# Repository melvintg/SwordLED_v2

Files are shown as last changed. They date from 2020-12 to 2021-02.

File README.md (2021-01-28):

# SwordLED_v2
Arduino LED system embeded in a softcombat sword.
Features:
- BMS for 2S 18650 batteries with automatic cell balance.
- 2S 18650 charger (Vin=12V).
- 5V Buck converter up to 3A
- Arduino ATmega328P with USB
- Bluetooth module HC-06
- 3 axis Accel/gyro MPU-6050
- Touch sensitive button & beeper.

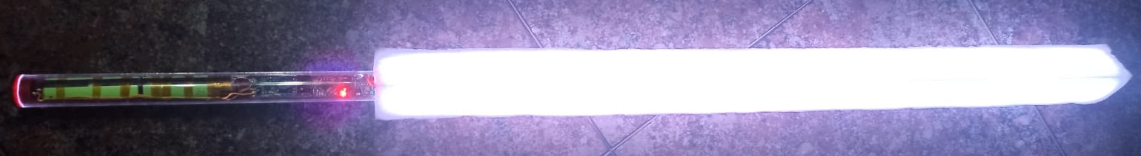
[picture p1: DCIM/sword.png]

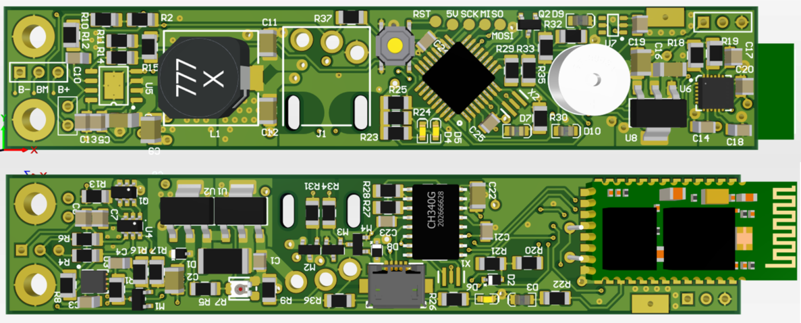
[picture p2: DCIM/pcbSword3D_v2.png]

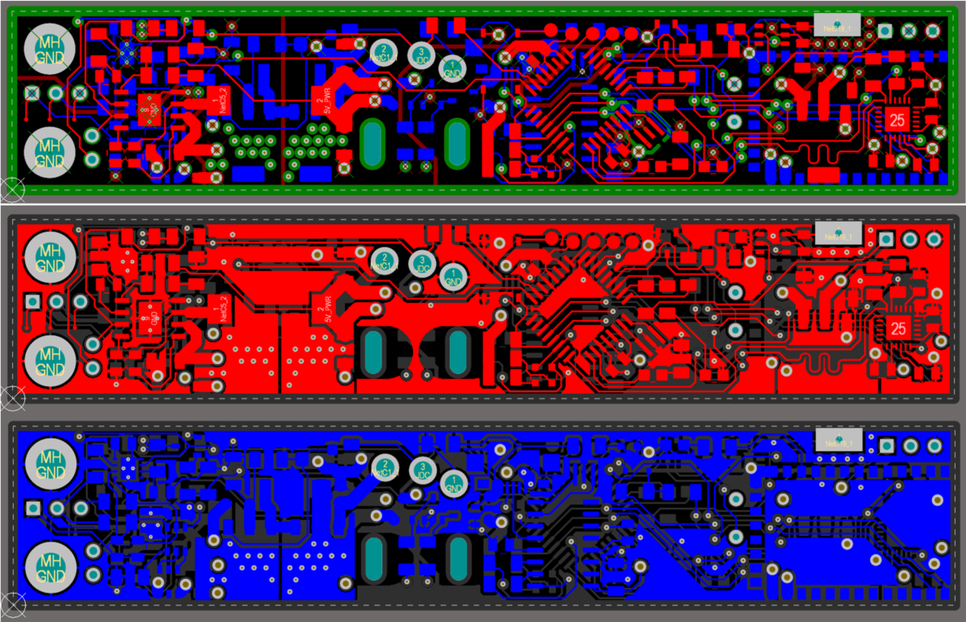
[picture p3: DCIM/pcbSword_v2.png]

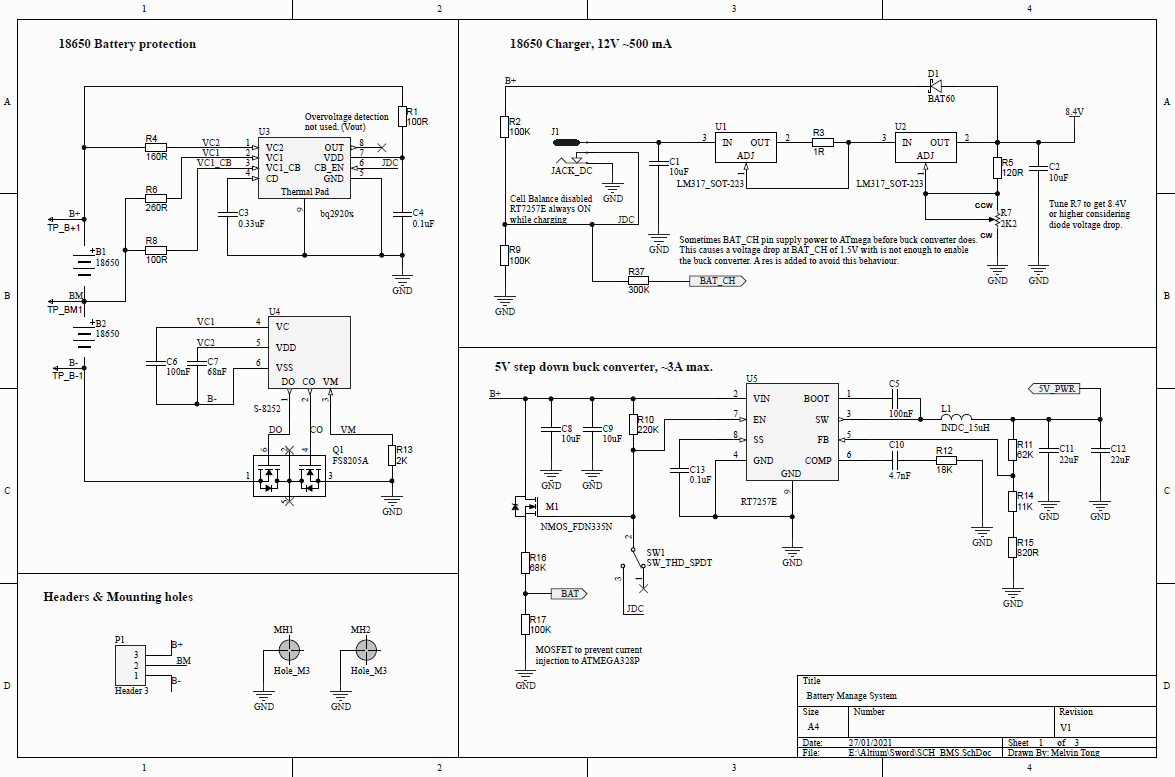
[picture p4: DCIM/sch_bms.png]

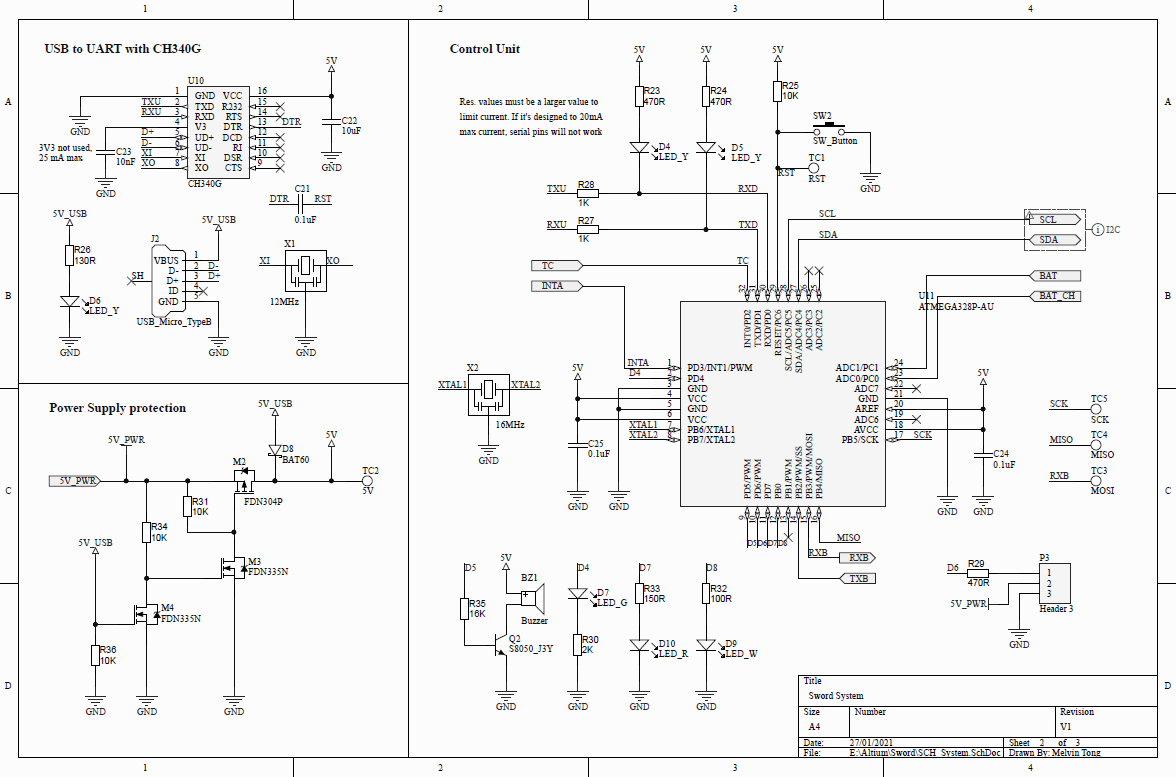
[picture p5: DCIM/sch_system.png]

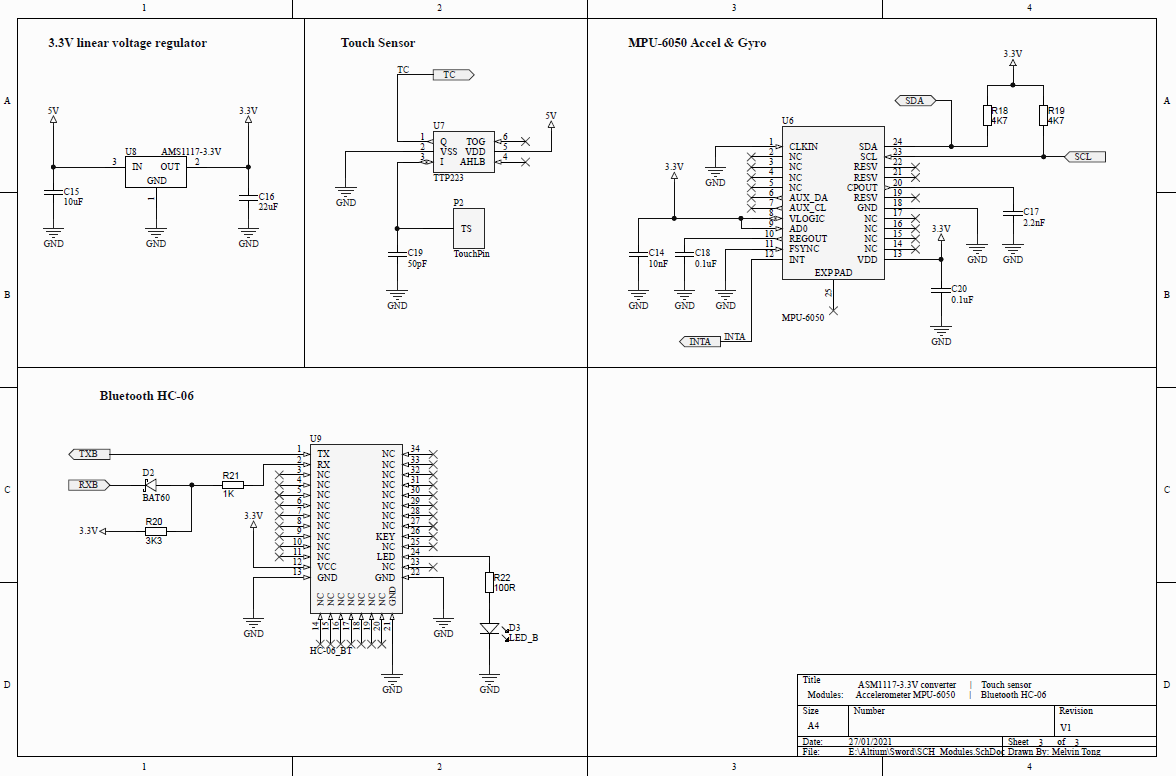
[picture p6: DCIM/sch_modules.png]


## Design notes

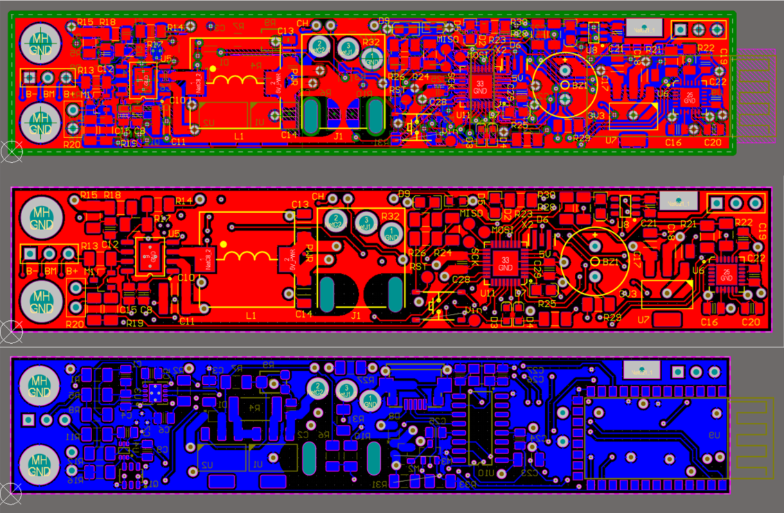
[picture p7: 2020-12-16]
DCIM/pcbSword.png

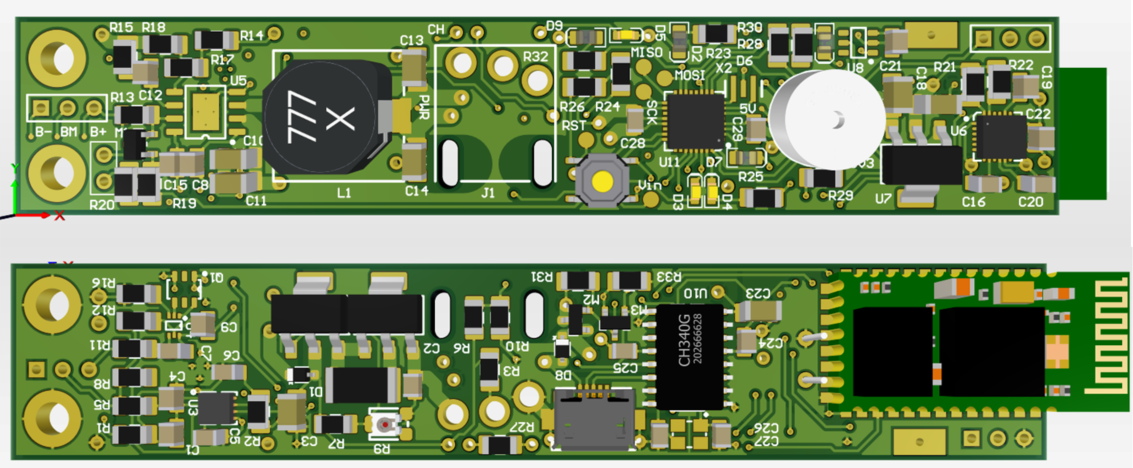
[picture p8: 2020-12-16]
DCIM/pcbSword3D.png

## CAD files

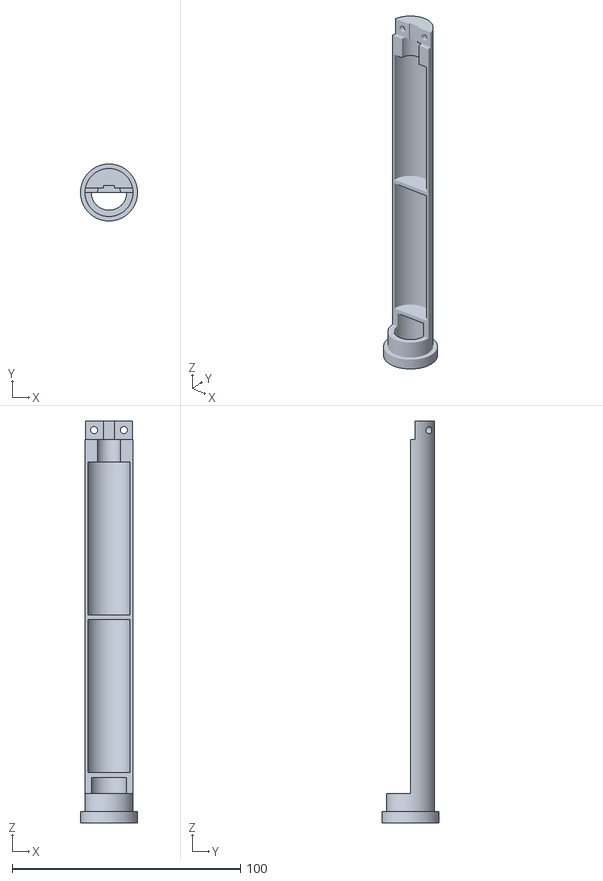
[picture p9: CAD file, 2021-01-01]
OpenSCADFiles/Sword.stl
25.0 x 25.0 x 176.0

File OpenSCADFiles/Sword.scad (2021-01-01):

$fn = 100;

// Variable declarations
dBase = 25;
hBase = 5;
dInnerBase = 21; // 25 - 2.8x2 thickness

dSW = 15.5;
dCapSW = 17;
hCapSW = 1.6;
hSW = 13;
hPinSW = 20;

hBat = 67;
dBat = 18.6;
dPinBat = 10;
hPinBat = 10;
hGapBat = 2;

yPcbGap = 2;
hPcbGap = 8;
pins2pcbGap = 8;
pinsHole = dInnerBase - pins2pcbGap*2;
hole2pcbGap = 4;
M3HoleCenter = (dInnerBase/2) - hole2pcbGap;
dM3Hole = 3.1;

hTotal = hPinSW+hBat*2+hGapBat*2+hPinBat+hPcbGap;


module Slot() {
    difference(){
    cylinder(h=hTotal,d=dInnerBase);
    translate([-dInnerBase/2,-dInnerBase,hSW])
        cube([dInnerBase,dInnerBase,hTotal]);
    }
}


module SW() {
    union(){
        cylinder(h=hPinSW,d=dSW);
        cylinder(h=hCapSW,d=dCapSW);
    }
}

module Base() {
    cylinder(h=hBase,d=dBase);
}

module Batteries() {
    translate([0,0,hPinSW+hGapBat])
        cylinder(h=hBat,d=dBat);
    translate([0,0,hPinSW+hGapBat*2+hBat])
        cylinder(h=hBat,d=dBat);
    translate([0,0,hPinSW+hGapBat*2+hBat*2])
        cylinder(h=hPinBat,d=dPinBat);
    
}

module PCB(){
    translate([-M3HoleCenter,dInnerBase/2,hTotal-hole2pcbGap])
        rotate([90,90,0])
            cylinder(h=dInnerBase,d=dM3Hole);
    translate([M3HoleCenter,dInnerBase/2,hTotal-hole2pcbGap])
        rotate([90,90,0])
            cylinder(h=dInnerBase,d=dM3Hole);
    translate([0,yPcbGap/2,hTotal-hPcbGap/2])
        cube([dInnerBase,yPcbGap,hPcbGap],true);
    translate([0,yPcbGap,hTotal-hPcbGap/2])
        cube([pinsHole,2,hPcbGap],true);
    
}

difference(){
    union(){
        Slot();
        Base();
    }
    SW();
    Batteries();
    PCB();
    /*
    translate([-dBase/2,-dInnerBase,0])
        cube([dBase,dInnerBase,hTotal]);
    */
}

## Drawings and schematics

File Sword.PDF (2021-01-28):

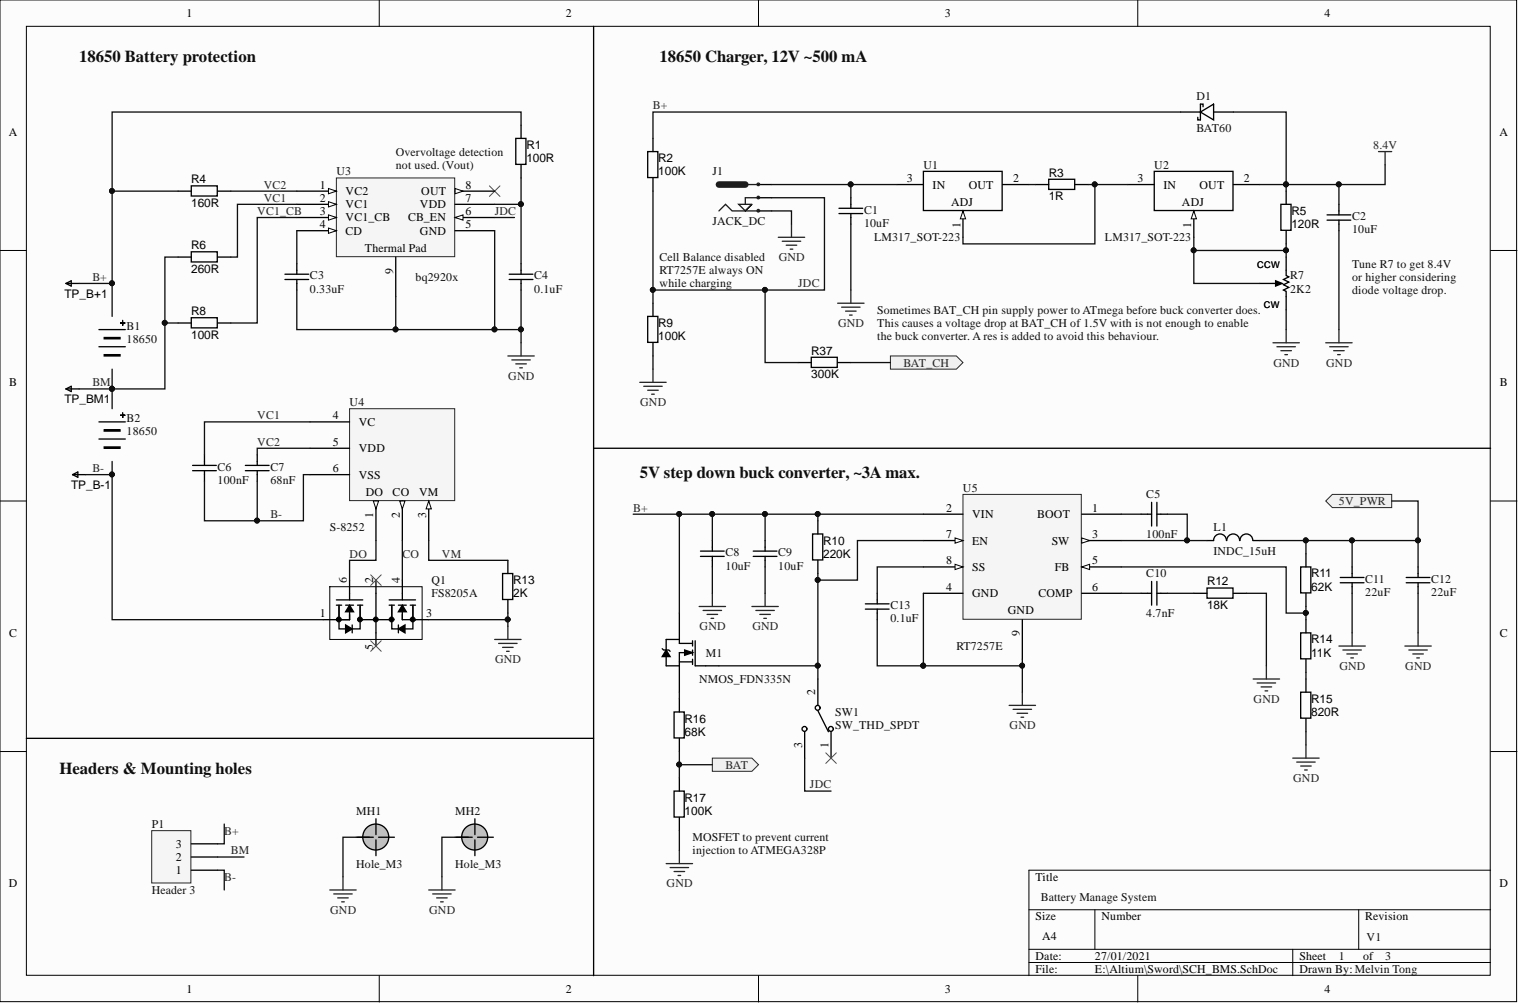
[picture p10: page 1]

Sometimes BAT_CH pin supply power to ATmega before buck converter does.
This causes a voltage drop at BAT_CH of 1.5V with is not enough to enable
the buck converter. A res is added to avoid this behaviour.

5V step down buck converter, ~3A max.

MOSFET to prevent current
injection to ATMEGA328P

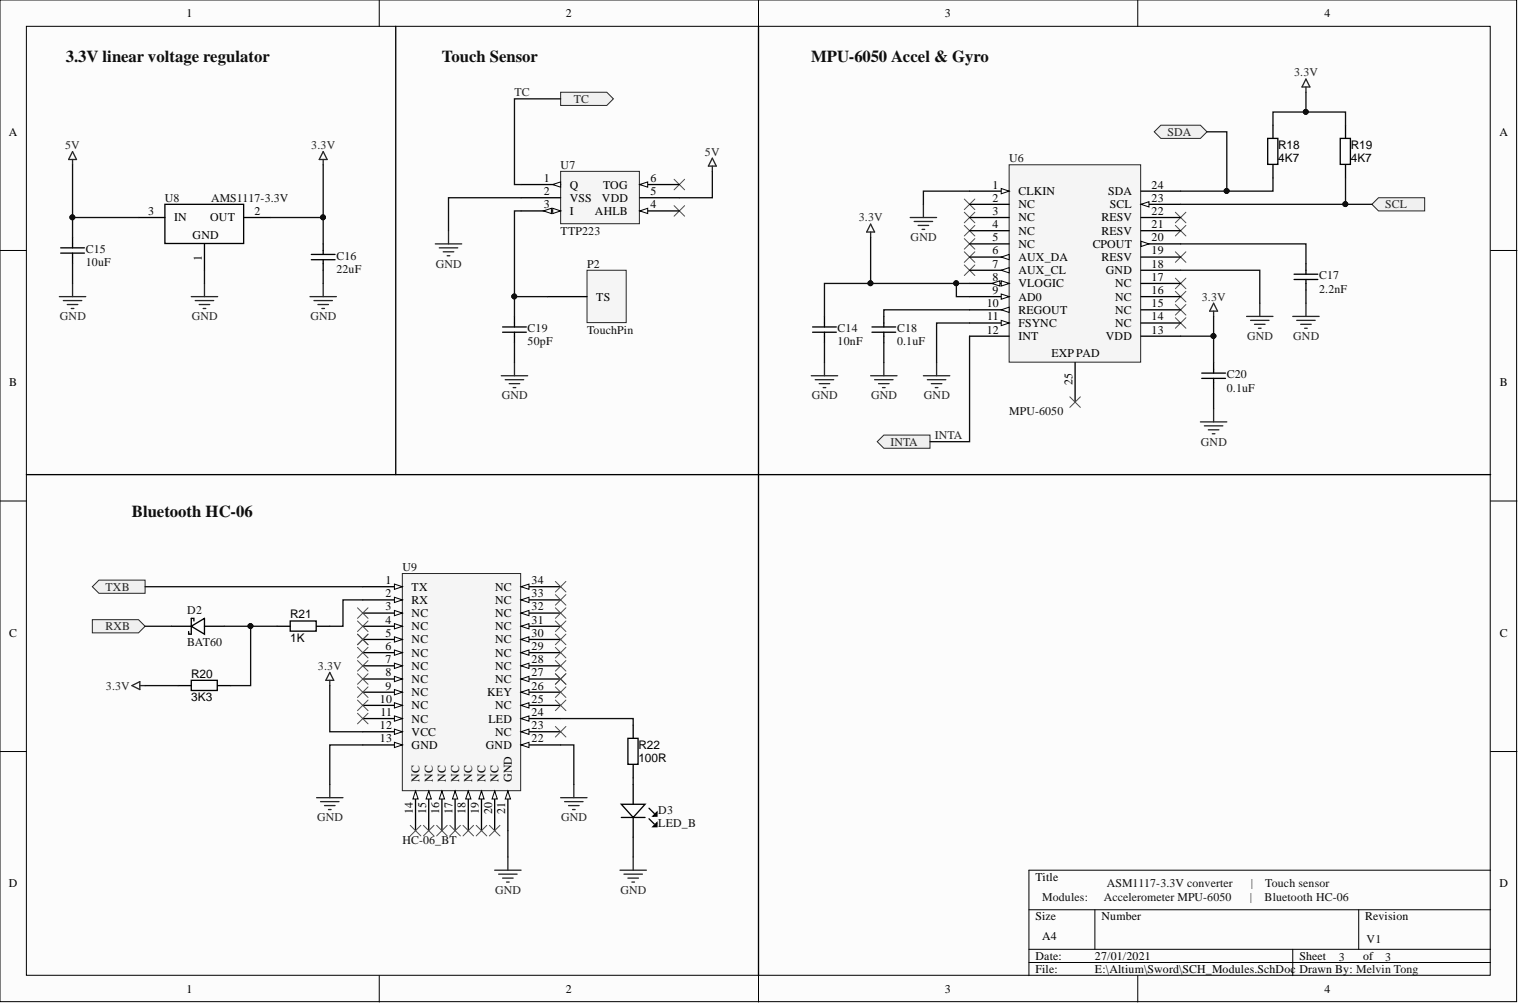
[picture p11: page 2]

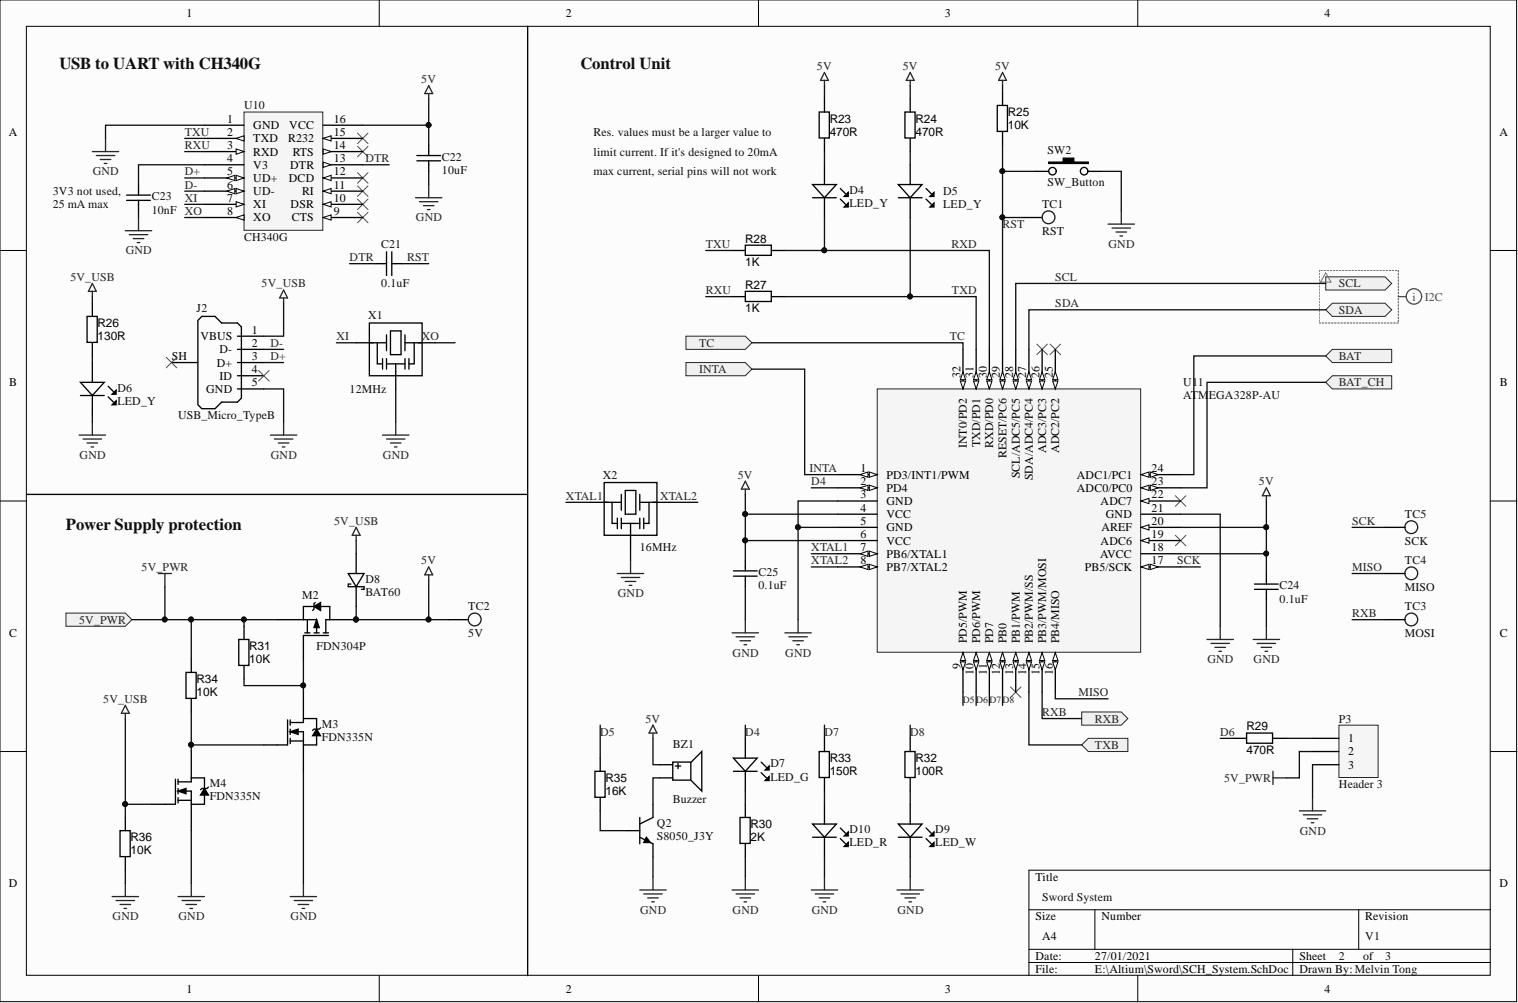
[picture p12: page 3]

limit current. If it's designed to 20mA
max current, serial pins will not work

ADC2/PC2 25 ADC3/PC3 26 SDA/ADC4/PC4 27 SCL/ADC5/PC5 28 RESET/PC6 29 RXD/PD0 30 TXD/PD1 31 INT0/PD2 32

GND 5

PB6/XTAL1 7 PB7/XTAL2 8

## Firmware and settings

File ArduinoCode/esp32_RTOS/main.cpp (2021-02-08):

#include <Arduino.h>

#include <Wire.h>
#include <FastLED.h>

static const uint8_t PIN_TS = 4;          // Touch Sensor
static const uint8_t PIN_LED_W = 15;       // LED White for Touch Sensor 8
static const uint8_t PIN_LED_G = 23;       // LED Green for ATmega328P
static const uint8_t PIN_BZ = 19;          // Buzzer
static const uint8_t PIN_LEDS = 18;        // LEDs WS2812B Data pin
static const uint8_t PIN_LED_R = 5;       // LED Red for Battery check
static const uint8_t PIN_TXB = 17;        // Tx Bluetooth
static const uint8_t PIN_RXB = 16;        // Rx Bluetooth
static const uint8_t PIN_BAT_CH = 2;     // Charge pin LOW/HIGH
static const uint8_t PIN_BAT = 0;        // Battery level

//#define MPU6050
#define BT06

#ifdef BT06
  //HardwareSerial BT(2);
  #include "BluetoothSerial.h"
  BluetoothSerial BT;
  void xBT(void *pvParam);
#endif

static const int VBAT = 421;
static const uint8_t TS_THRESHOLD = 40;

static const int DELAY_LED_R_FAST = 200;
static const int DELAY_LED_R_SLOW = 500;
static const uint8_t DELAY_LED_G = 200;
static const uint8_t DELAY_IMPACT = 15;
static const uint8_t DELAY_BAT_CHECK = 200;
static const uint8_t DELAY_BZ = 4;
static const uint8_t DELAY_LED_FADE_ON = 10;
static const uint8_t DELAY_LED_FADE_OFF = 10;
static const uint8_t DELAY_LED_WAVE = 4;
static const uint8_t DELAY_HG_WAVE = 4;
static const uint8_t DELAY_HG_BLINK = 80;
static const uint8_t DELAY_FAST_BLINK = 15;
static const uint8_t DELAY_BT = 5;
static const uint8_t DELAY_MPU6050 = 5;

// Bluetooth global variables
static volatile boolean g_bBTa = false;

// MPU6050 global variables
#ifdef MPU6050
typedef struct Accelerometer {
  float S;       // Sensitivity
  float X;
  float Y;
  float Z;
  float angleX;
  float angleY;
  float errorX;
  float errorY;
  unsigned long elapsedTime;
  unsigned long currentTime;
  unsigned long PrevTime;
} Acc_t;
static Acc_t *g_pAcc;

typedef struct Gyroscope {
  float S;       // Sensitivity
  float X;
  float Y;
  float Z;
  float angleX;
  float angleY;
  float angleZ;
  float errorX;
  float errorY;
  float errorZ;
  float Roll;
  float Pitch;
  float Yaw;
} Gyro_t;
static Gyro_t *g_pGyro;

void xReadMPU6050(void *pvParam);
#endif

// LED animations using Accel.
typedef struct AccelAnimations {
  byte nImact;        // Impact Action
  boolean bAgr;       // Agressive Action
  boolean impDetect;  // Impact detected
  boolean agrDetect;  // Agressive detected
  boolean bLG;        // Low guard
  boolean bDG;        // Defensive guard
  boolean bHG;        // High guard
  byte tHG;           // High guard wave time
  byte delayTime;     // High guard refresh time
  int nHG;            // High guard counter
} AccFx_t;
static AccFx_t *g_pAccFx;

// LED fade Animation variables
typedef struct LedFade {
  byte progress;
  byte waveCount;
  boolean isWaveInv;
  byte delayTime;
  byte fadeValue;
} LedFade_t;
static LedFade_t *g_pLedFade;

// LED wave Animation variables
typedef struct LedWave {
  byte progress = 0;
  byte delayTime = 0;
  byte fadeValue = 0;
} LedWave_t;
static LedWave_t *g_pLedWave;

// Battery Check variables
typedef struct BatCheck {
  boolean active;
  boolean mantained;
  boolean led;
  int delayTime;
} BatCheck_t;
static BatCheck_t *pBatCheck;

// WS2812B Constants and variables
static const uint8_t NUM_LEDS = 44;
static const uint8_t NUM_COLOR = 5;
static CRGB Leds[NUM_LEDS];
static CRGB TargetLeds[NUM_LEDS];
static const CRGB COLOR[NUM_COLOR] = {CRGB::White, CRGB::Orange, CRGB::Blue, CRGB::HotPink,  CRGB::Green};
static volatile uint8_t ColorPos;
static CRGB g_CurrentColor;

// Constant definitions
static const uint8_t MPU = 0x68;
static const uint8_t NUM_IMPACT = 14;

// Global flags variables
static volatile boolean g_bTs;
static volatile boolean g_bMantainedTS;
static volatile boolean g_bLEDs;
static volatile boolean g_bLEDg;
static volatile boolean g_bSword;
static volatile boolean g_bFastLedBlink;
static volatile boolean g_bBz;

// Global variables
static volatile unsigned long g_time;
static volatile unsigned long g_touchTime;
static volatile uint8_t g_nTouch;
static volatile int g_nBz;

void setupVariables(void);

// Touch sensor function prototypes
void touchSensor(void);

// LED on/off function prototypes
void ledON(CRGB color, int nLeds);
void ledOFF(void);

int askBat(void);

void startLedWave(byte fadeVal, byte delayTime);
void startLedFade(CRGB color, byte fadeVal, byte delayTime, int wave);
void ledFadeAll(int fadeVal);
CRGB fadeTowardColor( CRGB& cur, const CRGB& target, uint8_t amount);
void nblendU8TowardU8( uint8_t& cur, const uint8_t target, uint8_t amount);

void xCheckTS(void *parameter);
void xLedGreen(void *parameter);
void xCheckBattery(void *pvParam);
void xFastLedBlink(void *pvparam);
void xAskBat(void *pvParam);
void xSwordImpact(void *pvParam);
void xLedWave(void *pvParam);
void xLedFade(void *pvParam);

void startBzFade(boolean isFadeON);
void xBzFadeON(void *pvParam);
void xBzFadeOFF(void *pvParam);
void startBzWave(boolean isInv);
void xBzWave(void *pvParam);
void xBzWaveInv(void *pvParam);
void bzBlink(int f);
void startLedHighGuard(void);
void xLedHighGuard(void *pvParam);

static TaskHandle_t xAskBat_Hdlr;
static TaskHandle_t xLedsBlink_Hdlr;

static SemaphoreHandle_t LedsMutex;
static SemaphoreHandle_t BzMutex;

void setupVariables() {

#ifdef MPU6050
g_pAcc = (Acc_t*) pvPortMalloc(sizeof(Acc_t));
g_pGyro = (Gyro_t*) pvPortMalloc(sizeof(Gyro_t));
#endif

  g_pLedFade = (LedFade_t*) pvPortMalloc(sizeof(LedFade_t));
  g_pLedWave = (LedWave_t*) pvPortMalloc(sizeof(LedWave_t));
  pBatCheck = (BatCheck_t*) pvPortMalloc(sizeof(BatCheck_t));
  pBatCheck->active = 0;
  pBatCheck->delayTime = DELAY_LED_R_FAST;
  pBatCheck->led = false;


  // LED animations using Accel.
  g_pAccFx = (AccFx_t*) pvPortMalloc(sizeof(AccFx_t));
  g_pAccFx->nImact = 0;
  g_pAccFx->nHG = 0;
  g_pAccFx->tHG = DELAY_HG_WAVE;
  g_pAccFx->delayTime = DELAY_HG_BLINK;
  g_pAccFx->bHG = false;
  g_pAccFx->bLG = false;
  g_pAccFx->bDG = false;
  g_pAccFx->bAgr = false;
  g_pAccFx->impDetect = false;
  g_pAccFx->agrDetect = false;

  g_bLEDs = false;
  g_bLEDg = true;
  g_bSword = false;
  g_bBz = false;
  g_bFastLedBlink = false;
  g_bTs = false;
  g_bMantainedTS = false;

  g_nTouch = 0;
  g_nBz = 0;
  g_time =  0;
  g_touchTime = 0;
}

void setup() {

  setupVariables();

  // Configure pin
  pinMode(PIN_TS, INPUT);
  pinMode(PIN_LED_W, OUTPUT);
  pinMode(PIN_LED_G, OUTPUT);
  pinMode(PIN_LEDS, OUTPUT);
  pinMode(PIN_LED_R, OUTPUT);
  pinMode(PIN_BAT_CH, INPUT);
  pinMode(PIN_BAT, INPUT);

  digitalWrite(PIN_LED_W, LOW);
  digitalWrite(PIN_LED_G, HIGH);
  digitalWrite(PIN_LED_R, LOW);

  ledcSetup(0, 2000, 12);
  ledcAttachPin(PIN_BZ,0);

  touchAttachInterrupt(PIN_TS, touchSensor, TS_THRESHOLD);

  // See https://hackaday.com/2017/01/20/cheating-at-5v-ws2812-control-to-use-a-3-3v-data-line/
  FastLED.addLeds<WS2812, PIN_LEDS, GRB>(Leds, NUM_LEDS);
  LEDS.setBrightness(180);
  ColorPos = 0;
  g_CurrentColor = COLOR[ColorPos];
  ledOFF();

#ifdef MPU6050
  mpu6050setup();
#endif

#ifdef BT06
  BT.begin("esp32");
#endif

  Serial.begin(115200);
  vTaskDelay(1000 / portTICK_PERIOD_MS);
  Serial.println("Starting Sword");

  LedsMutex = xSemaphoreCreateMutex();
  BzMutex = xSemaphoreCreateMutex();

  // Start blink task
  xTaskCreatePinnedToCore(      // Use xTaskCreate() in vanilla FreeRTOS
            xLedGreen,          // Function to be called
            "Blink Green LED",  // Name of task
            1024,               // Stack size (bytes in ESP32, words in FreeRTOS)
            NULL,               // Parameter to pass
            1,                  // Task priority
            NULL,               // Task handle
            1);                 // Run on core one

  xTaskCreatePinnedToCore(          // Use xTaskCreate() in vanilla FreeRTOS
            xCheckTS,               // Function to be called
            "Check Touch Sensor",   // Name of task
            2048,                   // Stack size (bytes in ESP32, words in FreeRTOS)
            NULL,                   // Parameter to pass
            2,                      // Task priority
            NULL,                   // Task handle
            1);                     // Run on core one

  xTaskCreatePinnedToCore(  // Use xTaskCreate() in vanilla FreeRTOS
            xCheckBattery,    // Function to be called
            "Check Battery",  // Name of task
            1024,             // Stack size (bytes in ESP32, words in FreeRTOS)
            NULL,             // Parameter to pass
            1,                // Task priority
            NULL,             // Task handle
            1);               // Run on core one

#ifdef BT06
  xTaskCreatePinnedToCore(    // Use xTaskCreate() in vanilla FreeRTOS
            xBT,              // Function to be called
            "Read BT",        // Name of task
            2024,             // Stack size (bytes in ESP32, words in FreeRTOS)
            NULL,             // Parameter to pass
            2,                // Task priority
            NULL,             // Task handle
            0);               // Run on core zero
#endif

#ifdef MPU6050
  xTaskCreatePinnedToCore(    // Use xTaskCreate() in vanilla FreeRTOS
            xReadMPU6050,     // Function to be called
            "Read MPU6050",   // Name of task
            3072,             // Stack size (bytes in ESP32, words in FreeRTOS)
            NULL,             // Parameter to pass
            1,                // Task priority
            NULL,             // Task handle
            0);               // Run on core zero
#endif


  // If this was vanilla FreeRTOS, you'd want to call vTaskStartScheduler() in
  // main after setting up your tasks.

  // Delete "setup and loop" task
  vTaskDelete(NULL);
}


void loop() {
}

/* Interrupt function for touch sensor */
void touchSensor() {
  if (!g_bTs) {
    g_bTs = true;
    g_touchTime = millis();
    g_time = 0;

    // Update state
    digitalWrite(PIN_LED_W, g_bTs);
    Serial.println(g_bTs);
  }
}

/****************************** LEDs functions ********************************

##############################################################################*/

/**************************** ON/OFF LEDs function ***************************/
void ledON(CRGB color, int nLeds) {
  g_CurrentColor = color;
  for(int i = 0; i < nLeds; i++) {
      Leds[i] = color;
  }
  for (int i = nLeds; i < NUM_LEDS; i++) {
    Leds[i] = CRGB::Black;
  }
  FastLED.show();
}

void ledOFF() {
  for(int i = 0; i < NUM_LEDS; i++) {
      Leds[i] = CRGB::Black;
  }
  FastLED.show();
}

/* Perfomr a pulse led wave animation */
void ledPulse() {
  if (g_bSword) {
    Serial.println("Pulse led wave animation...");
    startLedWave(235, DELAY_LED_WAVE);
    startBzWave(true);
  }
}

void ledDifuseChange() {
  Serial.println("Changing base color...");
  ColorPos++;
  if (ColorPos == NUM_COLOR) ColorPos = 0;

  if (g_bSword) {
    startLedFade(COLOR[ColorPos], 8, 0, 0);
    startBzWave(false);
  }
}

void ledFadeON() {
  Serial.println("Switching ON Sword..");
  g_bLEDs = true;
  g_bSword = true;
  ColorPos = 0;
  startLedFade(COLOR[ColorPos], 2, DELAY_LED_FADE_ON, 1);
  startBzFade(true);
}

void ledFadeOFF() {
  Serial.println("Switching OFF Sword..");
  g_bLEDs = false;
  g_bSword = false;
  startLedFade(CRGB::Black, 12, DELAY_LED_FADE_OFF, -1);
  startBzFade(false);
}

void ledNormal() {
  if (g_bSword) {
    Serial.println("Sword back to normal");
    g_bLEDs = true;
    startLedFade(COLOR[ColorPos], 8, 0, 0);
  }
  ledcWrite(0, 0);
}

// Fast lEDs blink motion
void fastLedBlink(CRGB color) {
  g_bLEDs = !g_bLEDs;
  if (g_bLEDs) {
    ledON(color, NUM_LEDS);
  } else {
    ledOFF();
  }
}

void ledAgressive() {
  Serial.println("Sword movement detected...");
  startLedFade(CRGB::Red, 8, 0, 1);
  startBzWave(true);
}

void ledLowGuard() {
  // Difuse to Green
  startLedFade(CRGB::Green, 8, 0, 1);
  startBzWave(false);
}

void ledDefenseGuard() {
  // Difuse to Blue
  startLedFade(CRGB::Blue, 8, 0, 1);
  startBzWave(false);
}


//*****************************************************************************
// Tasks
//*****************************************************************************

void xLedGreen(void *pvParam) {
  (void) pvParam;

  while (1) {
    // Blink Green LED while normal operation (excludes battery charging)
    if (digitalRead(PIN_BAT_CH)) {
      digitalWrite(PIN_LED_G, LOW);
    } else {
      g_bLEDg = !g_bLEDg;
      digitalWrite(PIN_LED_G, g_bLEDg);
    }
    vTaskDelay(DELAY_LED_G / portTICK_PERIOD_MS);
  }

  // Cannot be here. Delete task.
  vTaskDelete(NULL);
}

void xCheckTS(void *pvParam) {
  (void) pvParam;
  while (1) {

    // If timer is ON, update timer.
    if (g_touchTime != 0) g_time = millis() - g_touchTime;

    if (touchRead(PIN_TS) > TS_THRESHOLD && g_bTs) {
      // Touch sensor released.
      g_bTs = false;

      // Check if it is a pulse or a maintained touch
      if (!g_bMantainedTS)  g_nTouch++;
      else                  g_touchTime = 0;
      g_bMantainedTS = false;

      // Battery check mantained press is released. End Battery check.
      if (pBatCheck->active) {
        Serial.println("End battery check.");
        pBatCheck->active = false;
        g_nTouch = 0;
        xSemaphoreGive(LedsMutex);
        vTaskDelete(xAskBat_Hdlr);
        ledNormal();
      }

        // Update state
      digitalWrite(PIN_LED_W, g_bTs);
      Serial.println(g_bTs);
    }

      // Touch Sensor High. Check for Maintained touch
    if (g_bTs) {

      // Check if Touch Sensor is mantained for 1000 ms
      if (g_time > 1000 && !g_bMantainedTS) {
        // Button maintained
        g_bMantainedTS = true;
        // Stop Timer
        g_touchTime = 0;
        // If only was one touch previously
        if (g_nTouch > 0) {
          Serial.println("1 press & 1 mantained Touch Sensor");
          pBatCheck->active = true;
          // Battery status Blink
          xTaskCreatePinnedToCore(  // Use xTaskCreate() in vanilla FreeRTOS
                    xAskBat,        // Function to be called
                    "Ask bat",      // Name of task
                    1024,           // Stack size (bytes in ESP32, words in FreeRTOS)
                    NULL,           // Parameter to pass
                    3,              // Task priority
                    &xAskBat_Hdlr,  // Task handle
                    1);             // Run on core one
        } else {
          Serial.println("1 mantained Touch Sensor");
          // Only maintained (ON/OFF)
          g_bSword = !g_bSword;
          if (g_bSword)  ledFadeON();
          else          ledFadeOFF();
        }
      }

    } else {

      // Touch Sensor Low. Check for n press.
      if (g_nTouch != 0) {
        // Wait for another Touch Sensor press. 200 ms
        if (g_time > 200) {
          // Stop Timer
          g_touchTime = 0;
          if (g_nTouch == 1) {
            Serial.println("1 press Touch Sensor");
            ledPulse();
          } else if (g_nTouch == 2) {
            Serial.println("2 press Touch Sensor");
            ledDifuseChange();
          } else {
            Serial.println("3 press Touch Sensor");
            g_bFastLedBlink = !g_bFastLedBlink;
            if (g_bFastLedBlink) {
              // Fast lEDs blink motion
              xTaskCreatePinnedToCore(        // Use xTaskCreate() in vanilla FreeRTOS
                        xFastLedBlink,        // Function to be called
                        "Fast LED blink",     // Name of task
                        1024,                 // Stack size (bytes in ESP32, words in FreeRTOS)
                        NULL,                 // Parameter to pass
                        3,                    // Task priority
                        &xLedsBlink_Hdlr,     // Task handle
                        1);                   // Run on core one
            } else {
              xSemaphoreGive(LedsMutex);
              vTaskDelete(xLedsBlink_Hdlr);
              ledNormal();
            }
          }
          g_nTouch = 0;
        }
      }
    }
    vTaskDelay(50 / portTICK_PERIOD_MS);
  }
  // Cannot be here. Delete task.
  vTaskDelete(NULL);
}

/* Indicates the battery state using a red LED blink animation */
void xCheckBattery(void *pvParam) {
  (void) pvParam;
  while(1) {
    int batValue = analogRead(PIN_BAT);
    // Due to NMOS voltage drop, each BAT value is previously measured.
    // Scale analog reading to voltage value up to two decimals.
    // 0-4095 -> 0-3.300V
    int val = map(batValue, 0, 4095, 0, 3300);

    // 100% -> 4.2Vbat | 80% -> 3.9Vbat | 60% -> 3.8Vbat | 40% -> 3.7Vbat | 20% -> 3.6Vbat | 0% -> 3Vbat
    if (digitalRead(PIN_BAT_CH)) {
      // Charge mode
      if (val < VBAT-7*4) { // 7.5 Vbat -> 3.72v
        // LED_R blink slow for battery 0%-50%
        pBatCheck->delayTime = DELAY_LED_R_SLOW;

        pBatCheck->led = !pBatCheck->led;
        digitalWrite(PIN_LED_R, pBatCheck->led);

      } else if (val < VBAT+20) { // 7.8 Vbat -> 3.89v
        // LED_R blink fast for battery 50%-90%
        pBatCheck->delayTime = DELAY_LED_R_FAST;

        pBatCheck->led = !pBatCheck->led;
        digitalWrite(PIN_LED_R, pBatCheck->led);
      } else {
        // LED_R ON for battery 80%-100%
        digitalWrite(PIN_LED_R, HIGH);
      }
    } else {
      // Normal mode
      if (val > VBAT-7*5) { // 7.4 Vbat -> 3.64v
        // LED_R OFF for battery 100%-40%
        digitalWrite(PIN_LED_R, LOW);

      } else if (val > VBAT-7*7) { // 7.2 Vbat -> 3.52v
        // LED_R blink slow for battery 40%-20%
        pBatCheck->delayTime = DELAY_LED_R_SLOW;

        pBatCheck->led = !pBatCheck->led;
        digitalWrite(PIN_LED_R, pBatCheck->led);

      } else {
        // LED_R blink fast for battery 20%-0%
        pBatCheck->delayTime = DELAY_LED_R_FAST;

        pBatCheck->led = !pBatCheck->led;
        digitalWrite(PIN_LED_R, pBatCheck->led);
      }
    }
   vTaskDelay(pBatCheck->delayTime / portTICK_PERIOD_MS);
  }
  // Cannot be here. Delete task.
  vTaskDelete(NULL);
}


/******************************* Sword animation *****************************
##############################################################################

##############################################################################*/

// Fast lEDs blink motion
void xFastLedBlink(void *pvParam) {
  (void) pvParam;

  xSemaphoreTake(LedsMutex, portMAX_DELAY);

  while(1) {
  	fastLedBlink(g_CurrentColor);
  	vTaskDelay(DELAY_FAST_BLINK / portTICK_PERIOD_MS);
  }

  // Cannot be here. Delete task.
  vTaskDelete(NULL);
}


/************************** Battery Check animation **************************/
void xAskBat(void *pvParam) {
  (void) pvParam;

  xSemaphoreTake(LedsMutex, portMAX_DELAY);
  while(1) {
    // Battery check with Touch Sensor
    int nLEDs = askBat();

    if (g_bLEDs) {
      ledON(CRGB::Red, nLEDs);
    } else {
      ledOFF();
    }
    g_bLEDs = !g_bLEDs;

    vTaskDelay(DELAY_BAT_CHECK / portTICK_PERIOD_MS);
  }
  // Cannot be here. Delete task.
  vTaskDelete(NULL);

}

/*************************** Impact Sword animation **************************/
/* Impact detected. Start led and buzzer blink animation. */
void startSwordImpact() {
  g_pAccFx->nImact = NUM_IMPACT;
  xTaskCreatePinnedToCore(        // Use xTaskCreate() in vanilla FreeRTOS
            xSwordImpact,         // Function to be called
            "Impact",             // Name of task
            1024,                 // Stack size (bytes in ESP32, words in FreeRTOS)
            NULL,                 // Parameter to pass
            4,                    // Task priority
            NULL,                 // Task handle
            1);                   // Run on core one
}


void xSwordImpact(void *pvParam) {
  (void) pvParam;

  xSemaphoreTake(LedsMutex, portMAX_DELAY);
  xSemaphoreTake(BzMutex, portMAX_DELAY);

  while (g_pAccFx->nImact > 1) {
    fastLedBlink(CRGB::Yellow);
    bzBlink(2000);
    g_pAccFx->nImact--;

    vTaskDelay(DELAY_IMPACT / portTICK_PERIOD_MS);
  }

  xSemaphoreGive(LedsMutex);
  xSemaphoreGive(BzMutex);

  // Last impact. Get to Normal
  ledNormal();
  g_pAccFx->nImact = 0;

  // Delete Task
  vTaskDelete(NULL);
}

/***************************** Wave LED animation ****************************/
void startLedWave(byte fadeVal, byte delayTime) {

  Serial.println("Starting Wave...");

  g_pLedWave->delayTime = delayTime;
  if (delayTime == 0) g_pLedWave->delayTime = 1;   // Some delay for stability
  g_pLedWave->fadeValue = fadeVal;
  g_pLedWave->progress = 0;

  xTaskCreatePinnedToCore(  // Use xTaskCreate() in vanilla FreeRTOS
            xLedWave,       // Function to be called
            "Led Wave",     // Name of task
            1024,           // Stack size (bytes in ESP32, words in FreeRTOS)
            NULL,           // Parameter to pass
            2,              // Task priority
            NULL,           // Task handle
            1);             // Run on core one
}

void xLedWave(void *pvParam) {
  (void) pvParam;

  xSemaphoreTake(LedsMutex, portMAX_DELAY);
  while (g_pLedWave->progress < NUM_LEDS) {
    Leds[g_pLedWave->progress].maximizeBrightness();
    ledFadeAll(g_pLedWave->fadeValue);
    FastLED.show();
    g_pLedWave->progress++;

    vTaskDelay(g_pLedWave->delayTime / portTICK_PERIOD_MS);
  }
  xSemaphoreGive(LedsMutex);
  // vPortFree(g_pLedWave);
  Serial.println("Ending Wave...");

  startLedFade(g_CurrentColor, 8, 0, 0);

  // Delete Task
  vTaskDelete(NULL);
}

/* Fade all LEDs value by (fadeVal/256ths) of its previous value
   Doc. https://github.com/FastLED/FastLED/wiki/Pixel-reference */
void ledFadeAll(int fadeVal) {
  for(int i = 0; i < NUM_LEDS; i++) {
    Leds[i].nscale8_video(fadeVal);
  }
}
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

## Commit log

2020-12-16 Altium PCB Design added.
    [BMS.SchDoc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]
2020-12-16 pcb images added
2020-12-21 Some LED functions added.
2020-12-29 New design implemented.
    - NMOS and S-8252 footprint error fixed.
    - New BMS design with fewer components.
    - ATMEGA328P-MU to ATMEGA328P-AU footprint changed.
    - Charge battery detection by DC power plug.
    - System always ON while charging to check battery.
    - USB ports D+/- error fixed.
    - Series resistor added in TXD/RXD.
    - TxB circuit protection added (for working at 3.3V)
    - CH340G 12 MHz crystal oscillator changed. No caps needed.
    - MPU6050 interrupt added.
    - PMOS added for lower voltage drop.
    - Thermal dissipation with Via Stitching added to 18650 charge circuit.
    - Touch sensor pad shielding added.
    - Connection style changed.
    [PCB_Sword.PcbDoc, PcbLib_Sword.PcbLib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]
2021-01-01 PCB height slot added.
    [Sword.scad, Sword.stl]
2021-01-26 Minor changes and bug fixing
    - Serial Resistor changed
    - Blue & green LED resistors changed.
    - Resistor added at pin BAT_CH
    - Change thermal disipation pad at LM317 & ASM1117
    - Bug Fix at B+ & BM -> S-8252 pins.
    - USB socket not shielded to gnd.
    - Bigger via added at 5V_PWR -> 5V
    - Vin Buck converter Capacitors distribution changed.
    - Polygons changed to have a better thermal disipation.
    [PCB_Sword.PcbDoc, SCH_BMS.SchDoc, SCH_Modules.SchDoc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]
2021-01-27 Rearrange and label sch & i2c length matching
    [PCB_Sword.PcbDoc, PcbLib_Sword.PcbLib, SCH_BMS.SchDoc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]
2021-01-28 Buzzer functions and fast blink animation added.
    [sword.ino]
2021-02-08 freeRTOS sword code for Espressif esp32
